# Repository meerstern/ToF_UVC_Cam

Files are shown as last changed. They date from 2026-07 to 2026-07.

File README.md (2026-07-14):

# ToF UVC Camera Board

## Overview 
  * This is a ToF camera board equipped with the [AMS TMF8829 ToF sensor][1].  
  * Outputs 48x32 ToF data as a UVC webcam image.  
  * The microcontroller used is the RP2040.  
  * Source code using the Pico-SDK is available.
  * Measuring up to 1.4 m in high-resolution mode and up to 5.7 m in standard mode.

## Detailed Specifications
  * The USB port uses a Type-C connection.
  * The board is recognized as a UVC (USB Video Class) device with a resolution of 128x96.
  * The ToF resolution is 48x32 as a UVC webcam image.
  * It is displayed scaled up by a factor of two(96x64).
  * Measuring up to 1.4 m in high-resolution mode(SW3 SEN ON)
  * Measuring up to 5.7 m in standard mode(SW3 SEN OFF)
  * Switch the color scale between absolute(SW3 ABS ON) and relative modes(SW3 ABS OFF).
  * In the relative mode, the color scale is calculated based on the overall maximum and minimum values.
  * For absolute mode, the color scale is calculated based on a minimum of 0 and a maximum of 1.4 m in high-resolution mode, or 5.7 m in normal mode.
  * If horizontally flip the output image, please flash the `UVC_RP2040_XXXXXX_vXX_Mirror.uf2` file.
  * In the code, enable `MIRRR_OUTPUT_MODE` in `UVC_RP2040.h`.
  * If the confidence value is less than 10, it will be displayed in black. 
  * The frame rate depends on the conditions, but it is around 8 FPS.
  * 80° FOV, 1cm minimum distance and 0.25 mm resolution
  * Power 5V/0.2A from USB Type-C Port
  * The maximum range of 11m is supported only at 8x8 resolution; this board does not support it.
  * The board size is 40mm x50 mm, the hole size is M3x4, the hole pitch is 34mm x44mm.
  * The sensor area on the board becomes hot. Please be careful.   

## Laser eye safety
The TMF8829 is designed to meet the Class 1 laser safety limits including single faults in
compliance with IEC / EN 60825-1:2014, EN 60825-1:2014+A11:2021 and Class 1 consumer
laser product according to EN 50689:2021.

## Updating the firmware
  * Connect the device to a PC (or similar) via USB Type-C.
  * Then press the RST button while holding down the BOOT button.
  * The device will be recognized as a USB drive.  
  * You can update the firmware by copying the firmware file(*.uf2) to the recognized USB drive.

## Appearance and examples
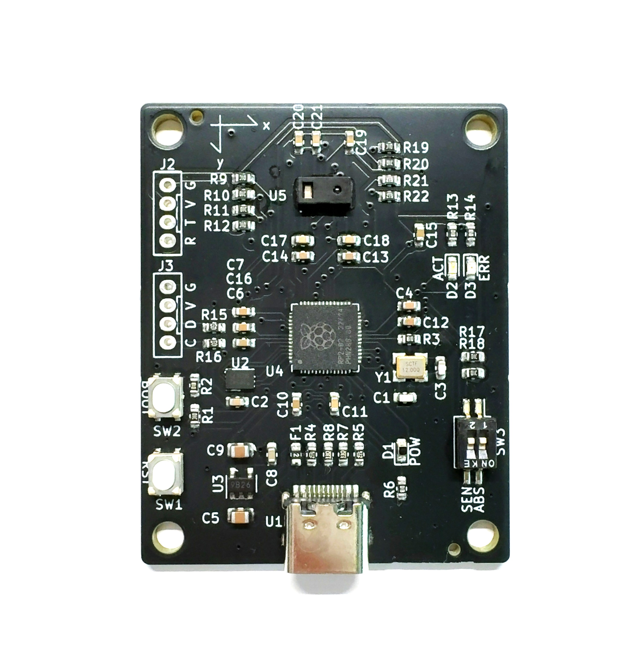
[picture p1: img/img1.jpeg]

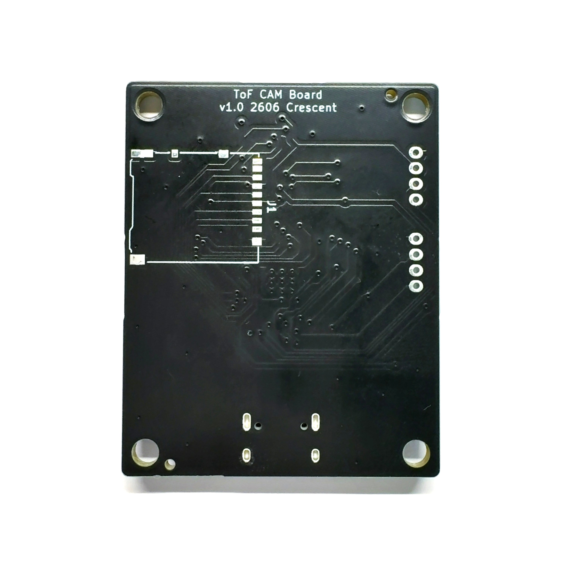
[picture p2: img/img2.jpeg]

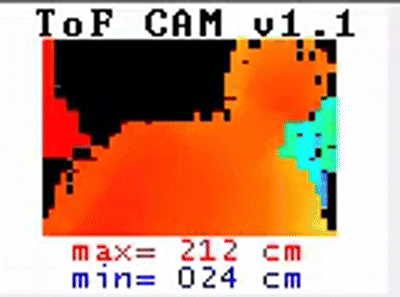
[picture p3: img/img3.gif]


[1]: https://ams-osram.com/ja/products/sensor-solutions/direct-time-of-flight-sensors-dtof/ams-tmf8829-48x32-multi-zone-time-of-flight-sensor

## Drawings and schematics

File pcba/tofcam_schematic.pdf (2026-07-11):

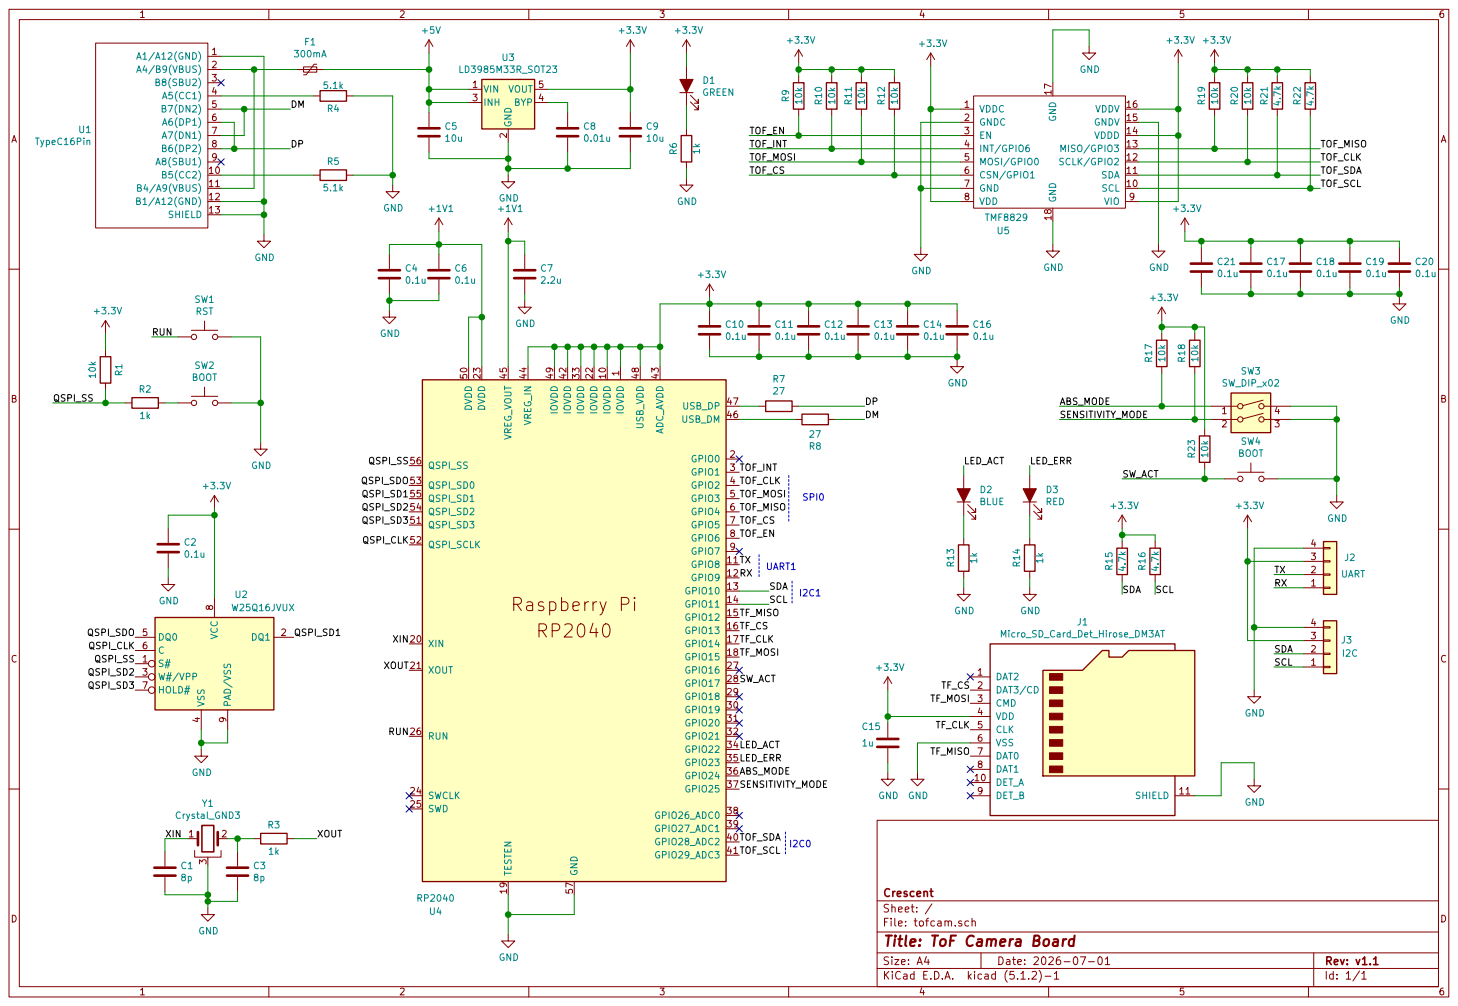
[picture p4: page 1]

1 IOVDD 10 GPIO8 11 GPIO9 12 GPIO10 13 GPIO11 14 GPIO12 15 GPIO13 16 GPIO14 17 GPIO15 18 TESTEN 19 GPIO0 2 XIN 20 XOUT 21 IOVDD 22 DVDD 23 SWCLK 24 SWD 25 RUN 26 GPIO16 27 GPIO17 28 GPIO18 29 GPIO1 3 GPIO19 30 GPIO20 31 GPIO21 32 IOVDD 33 GPIO22 34 GPIO23 35 GPIO24 36 GPIO25 37 GPIO26_ADC0 38 GPIO27_ADC1 39 GPIO2 4 GPIO28_ADC2 40 GPIO29_ADC3 41 IOVDD 42 ADC_AVDD 43 VREG_IN 44 VREG_VOUT 45 USB_DM 46 USB_DP 47 USB_VDD 48 IOVDD 49 GPIO3 5 DVDD 50 QSPI_SD3 51 QSPI_SCLK 52 QSPI_SD0 53 QSPI_SD2 54 QSPI_SD1 55 QSPI_SS 56 GND 57 GPIO4 6 GPIO5 7 GPIO6 8 GPIO7 9 U4 RP2040

File: tofcam.sch Sheet: / Crescent

Id: 1/1 Title: ToF Camera Board

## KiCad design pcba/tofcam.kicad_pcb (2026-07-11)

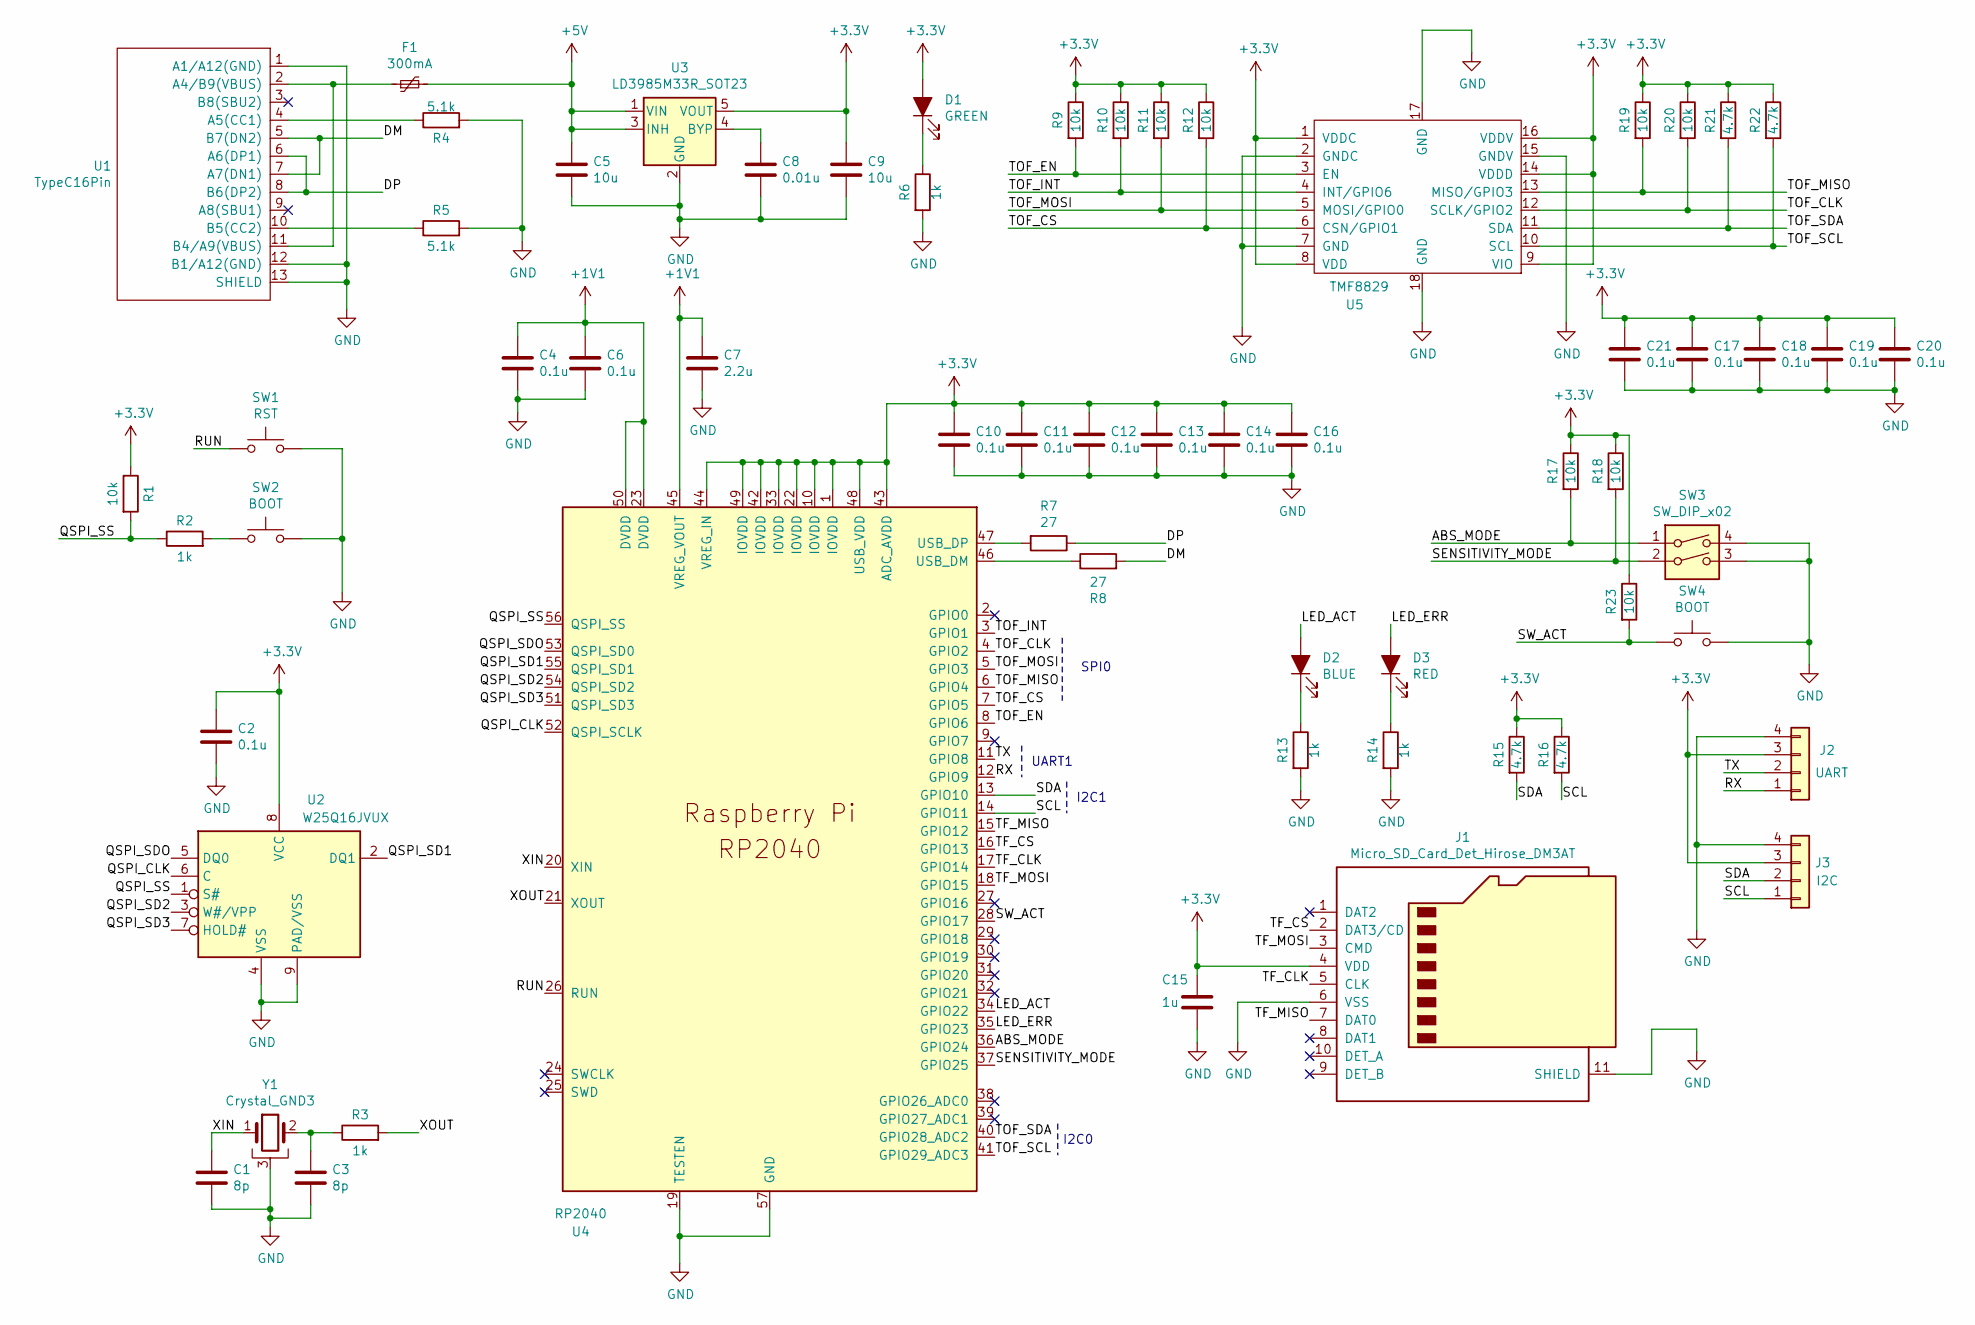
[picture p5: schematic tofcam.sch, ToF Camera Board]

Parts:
C1, C3: 8p; C_0603_1608Metric
C2, C4, C6, C10, C11, C12, C13, C14, C16, C17, C18, C19, C20, C21: 0.1u; C_0603_1608Metric
C5, C9: 10u; C_0805_2012Metric
C7: 2.2u; C_0603_1608Metric
C8: 0.01u; C_0603_1608Metric
C15: 1u; C_0603_1608Metric
D1: GREEN; LED_0603_1608Metric
D2: BLUE; LED_0603_1608Metric
D3: RED; LED_0603_1608Metric
F1: 300mA; Fuse_0603_1608Metric
J1: Micro_SD_Card_Det_Hirose_DM3AT; microSD_HC_Hirose_DM3AT-SF-PEJM5
J2: UART; GROVE
J3: I2C; GROVE
R1, R9, R10, R11, R12, R17, R18, R19, R20, R23: 10k; R_0603_1608Metric
R2, R3, R6, R13, R14: 1k; R_0603_1608Metric
R4, R5: 5.1k; R_0603_1608Metric
R7, R8: 27; R_0603_1608Metric
R15, R16, R21, R22: 4.7k; R_0603_1608Metric
SW1: RST; SKRPACE010
SW2, SW4: BOOT; SKRPACE010
SW3: SW_DIP_x02; SW_DIP_SPSTx02_Slide_Copal_CHS-02B_W7.62mm_P1.27mm
U1: TypeC16Pin; TypeC_16Pin
U2: W25Q16JVUX; SON-8-1EP_3x2mm_P0.5mm_EP1.4x1.6mm
U3: LD3985M33R_SOT23; SOT-23-5
U4: RP2040; RP2040-QFN-56
U5: TMF8829
Y1: Crystal_GND3; FA238V

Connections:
+1V1: C4.1, C6.1, C7.1, U4.23 (DVDD), U4.45 (VREG_VOUT), U4.50 (DVDD)
+3V3: C2.1, C9.1, C10.1, C11.1, C12.1, C13.1, C14.1, C15.1, C16.1, C17.1, C18.1, C19.1, C20.1, C21.1, D1.2 (A), J1.4 (VDD), J2.3, J3.3, R1.1, R9.1, R10.1, R11.1, R12.1, R15.1, R16.1, R17.1, R18.1, R19.1, R20.1, R21.1, R22.1, R23.1, U2.8 (VCC), U3.5 (VOUT), U4.1 (IOVDD), U4.10 (IOVDD), U4.22 (IOVDD), U4.33 (IOVDD), U4.42 (IOVDD), U4.43 (ADC_AVDD), U4.44 (VREG_IN), U4.48 (USB_VDD), U4.49 (IOVDD), U5.1 (VDDC), U5.8 (VDD), U5.9 (VIO), U5.14 (VDDD), U5.16 (VDDV)
+5V: C5.1, F1.2, U3.1 (VIN), U3.3 (INH)
/ABS_MODE: R17.2, SW3.1, U4.36 (GPIO24)
/DM: R8.2, U1.5 (B7(DN2)), U1.7 (A7(DN1))
/DP: R7.1, U1.6 (A6(DP1)), U1.8 (B6(DP2))
/LED_ACT: D2.2 (A), U4.34 (GPIO22)
/LED_ERR: D3.2 (A), U4.35 (GPIO23)
/QSPI_CLK: U2.6 (C), U4.52 (QSPI_SCLK)
/QSPI_SD1: U2.2 (DQ1), U4.55 (QSPI_SD1)
/QSPI_SD2: U2.3 (W#/VPP), U4.54 (QSPI_SD2)
/QSPI_SD3: U2.7 (HOLD#), U4.51 (QSPI_SD3)
/QSPI_SDO: U2.5 (DQ0), U4.53 (QSPI_SD0)
/QSPI_SS: R1.2, R2.1, U2.1 (S#), U4.56 (QSPI_SS)
/RUN: SW1.1, U4.26 (RUN)
/RX: J2.1, U4.12 (GPIO9)
/SCL: J3.1, R16.2, U4.14 (GPIO11)
/SDA: J3.2, R15.2, U4.13 (GPIO10)
/SENSITIVITY_MODE: R18.2, SW3.2, U4.37 (GPIO25)
/SW_ACT: R23.2, SW4.1, U4.28 (GPIO17)
/TF_CLK: J1.5 (CLK), U4.17 (GPIO14)
/TF_CS: J1.2 (DAT3/CD), U4.16 (GPIO13)
/TF_MISO: J1.7 (DAT0), U4.15 (GPIO12)
/TF_MOSI: J1.3 (CMD), U4.18 (GPIO15)
/TOF_CLK: R20.2, U4.4 (GPIO2), U5.12 (SCLK/GPIO2)
/TOF_CS: R12.2, U4.7 (GPIO5), U5.6 (CSN/GPIO1)
/TOF_EN: R9.2, U4.8 (GPIO6), U5.3 (EN)
/TOF_INT: R10.2, U4.3 (GPIO1), U5.4 (INT/GPIO6)
/TOF_MISO: R19.2, U4.6 (GPIO4), U5.13 (MISO/GPIO3)
/TOF_MOSI: R11.2, U4.5 (GPIO3), U5.5 (MOSI/GPIO0)
/TOF_SCL: R22.2, U4.41 (GPIO29_ADC3), U5.10 (SCL)
/TOF_SDA: R21.2, U4.40 (GPIO28_ADC2), U5.11 (SDA)
/TX: J2.2, U4.11 (GPIO8)
/XIN: C1.1, U4.20 (XIN), Y1.1
/XOUT: R3.2, U4.21 (XOUT)
GND: C1.2, C2.2, C3.2, C4.2, C5.2, C6.2, C7.2, C8.2, C9.2, C10.2, C11.2, C12.2, C13.2, C14.2, C15.2, C16.2, C17.2, C18.2, C19.2, C20.2, C21.2, J1.6 (VSS), J1.11 (SHIELD), J2.4, J3.4, R4.2, R5.2, R6.2, R13.2, R14.2, SW1.2, SW2.2, SW3.3, SW3.4, SW4.2, U1.1 (A1/A12(GND)), U1.12 (B1/A12(GND)), U1.13 (SHIELD), U2.4 (VSS), U2.9 (PAD/VSS), U3.2 (GND), U4.19 (TESTEN), U4.57 (GND), U5.2 (GNDC), U5.7 (GND), U5.15 (GNDV), U5.17 (GND), U5.18 (GND), Y1.3
unnamed: C3.1, R3.1, Y1.2
unnamed: C8.1, U3.4 (BYP)
unnamed: D1.1 (K), R6.1
unnamed: D2.1 (K), R13.1
unnamed: D3.1 (K), R14.1
unnamed: F1.1, U1.2 (A4/B9(VBUS)), U1.11 (B4/A9(VBUS))
unnamed: R2.2, SW2.1
unnamed: R4.1, U1.4 (A5(CC1))
unnamed: R5.1, U1.10 (B5(CC2))
unnamed: R7.2, U4.47 (USB_DP)
unnamed: R8.1, U4.46 (USB_DM)

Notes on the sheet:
I2C0
SPI0
UART1
I2C1

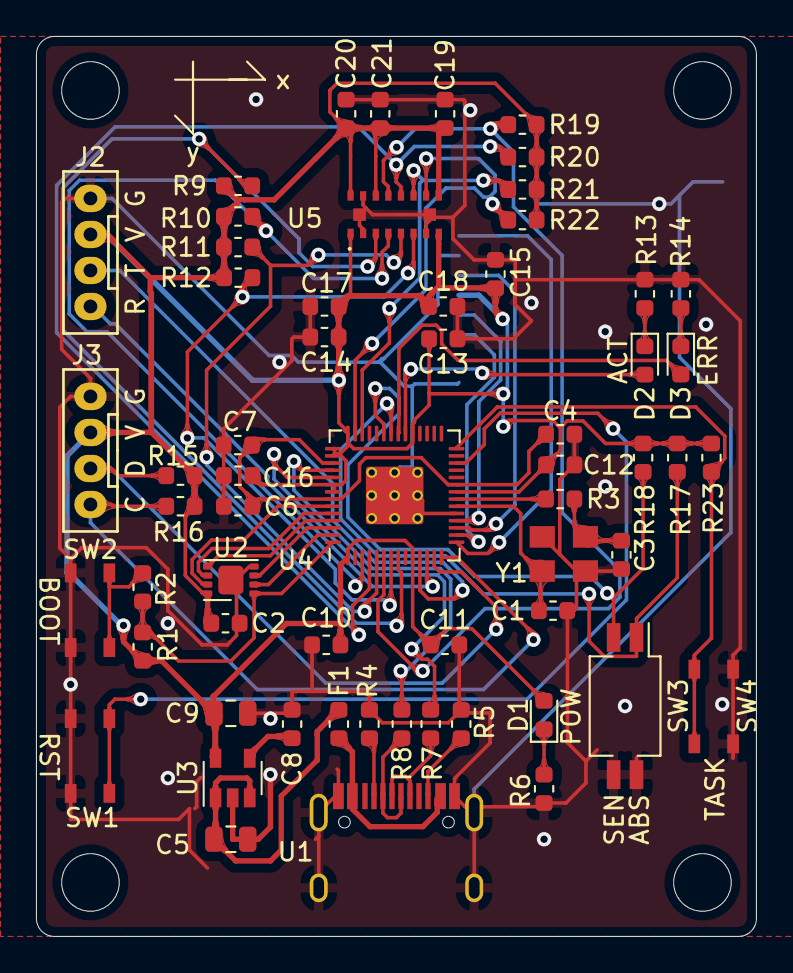
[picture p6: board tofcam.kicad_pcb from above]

Board: 2 copper layers, 40.0 x 50.0 mm, 65 parts (1 on the bottom side), 47 nets.

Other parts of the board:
REF1, REF2, REF3, REF4: MountingHole_3.2mm_M3

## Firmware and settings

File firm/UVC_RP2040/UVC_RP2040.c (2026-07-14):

/*
 * The MIT License (MIT)
 *
 * Copyright (c) 2019 Ha Thach (tinyusb.org)
 *
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
 */


#include <stdio.h>
#include <stdlib.h>
#include <stdbool.h>
#include <string.h>
#include <pico/stdlib.h>
#include <pico/rand.h>
#include <pico/multicore.h>

#include "bsp/board_api.h"
#include "tusb.h"
#include "usb_descriptors.h"
#include "ugui.h"
#include "UVC_RP2040.h"
#include "tmf8829.h"
#include "tmf8829_app.h"
#include "tmf8829_image.h"

UG_GUI gui;

static uint16_t guiBuff[FRAME_WIDTH*FRAME_HEIGHT];//RGB565

volatile uint8_t  tofBuff[TOF_PIX_WIDTH*TOF_PIX_HEIGHT*TOF_PIX_BYTES];
volatile uint16_t tofBuffIndex;
volatile bool     hasTofData = false;
volatile uint8_t  tofIndex;           //Index for interlace mode
static   bool     isTofReady = false;
         char     maxMinStr[40] = {'\0'};

#ifndef CFG_EXAMPLE_VIDEO_READONLY
// YUY2 frame buffer
static uint8_t frame_buffer[FRAME_WIDTH * FRAME_HEIGHT * 16 / 8];
#endif

//--------------------------------------------------------------------+
// MACRO CONSTANT TYPEDEF PROTYPES
//--------------------------------------------------------------------+

/* Blink pattern
 * - 250 ms  : device not mounted
 * - 1000 ms : device mounted
 * - 2500 ms : device is suspended
 */
enum {
  BLINK_NOT_MOUNTED = 250,
  BLINK_MOUNTED = 1000,
  BLINK_SUSPENDED = 2500,
};

static uint32_t blink_interval_ms = BLINK_NOT_MOUNTED;

void led_blinking_task(void* param);
void usb_device_task(void *param);
void video_task(void* param);


void pset(UG_S16 x, UG_S16 y, UG_COLOR col)
{
  uint16_t pix = 1*(x + y*FRAME_WIDTH);  
  guiBuff[pix] = col;
}

void copyFrameBuff()
{
  uint32_t pixels = FRAME_WIDTH * FRAME_HEIGHT;
  uint8_t *dst = &frame_buffer[0];

  for(uint32_t i = 0; i < pixels; i += 2)
  {
    uint16_t p0 = guiBuff[i];
    uint16_t p1 = guiBuff[i + 1];
     
    int r0 = (p0 >> 11) << 3;
    int g0 = ((p0 >> 5) & 0x3F) << 2;
    int b0 = (p0 & 0x1F) << 3;

    int r1 = (p1 >> 11) << 3;
    int g1 = ((p1 >> 5) & 0x3F) << 2;
    int b1 = (p1 & 0x1F) << 3;

    
    uint8_t y0 = (77 * r0 + 150 * g0 + 29 * b0) >> 8;
    uint8_t y1 = (77 * r1 + 150 * g1 + 29 * b1) >> 8;

    int u0 = ((-43 * r0 - 85 * g0 + 128 * b0) >> 8) + 128;
    int v0 = ((128 * r0 -107 * g0 - 21 * b0) >> 8) + 128;

    int u1 = ((-43 * r1 - 85 * g1 + 128 * b1) >> 8) + 128;
    int v1 = ((128 * r1 -107 * g1 - 21 * b1) >> 8) + 128;

    uint8_t u = (u0 + u1) >> 1;
    uint8_t v = (v0 + v1) >> 1;

    *dst++ = y0;
    *dst++ = u;
    *dst++ = y1;
    *dst++ = v;
  }
}

uint16_t val2rgb565( uint16_t value, uint16_t min, uint16_t max)
{
    if(value < min) value = min;
    if(value > max) value = max;

    uint32_t v = 255-((uint32_t)(value - min) * 255)/(max - min);
    uint8_t r, g, b;

    if(v < 64)
    {
        r = 0;
        g = v * 4;
        b = 255;
    }
    else if(v < 128)
    {
        r = 0;
        g = 255;
        b = 255 - (v - 64) * 4;
    }
    else if(v < 192)
    {
        r = (v - 128) * 4;
        g = 255;
        b = 0;
    }
    else
    {
        r = 255;
        g = 255 - (v - 192) * 4;
        b = 0;
    }

    return 
        ((r & 0xF8) << 8) |
        ((g & 0xFC) << 3) |
        (b >> 3);
}

void makeInitGrid()
{
  //return;
  uint16_t x,y;
  for(y=0;y<TOF_PIX_HEIGHT-1;y++)
  {
    for(x=0;x<TOF_PIX_WIDTH-1;x++)
    {
      uint16_t color = get_rand_32();
      uint16_t x_pos = START_X_POS + CELL_SIZE*x;
      uint16_t y_pos = START_Y_POS + CELL_SIZE*y;
      UG_FillFrame(x_pos, y_pos, x_pos+CELL_SIZE, y_pos+CELL_SIZE, color); 

    }
  }
}

void makeScaleGrid()
{
  uint16_t x,y;
  for(y=0;y<TOF_PIX_HEIGHT;y++)
  {
    uint16_t x_pos = START_X_POS + CELL_SIZE*TOF_PIX_WIDTH+5;
    uint16_t y_pos = START_Y_POS + CELL_SIZE*y;
    uint16_t color = val2rgb565(2*START_Y_POS+CELL_SIZE*TOF_PIX_HEIGHT-y_pos, START_Y_POS, START_Y_POS+CELL_SIZE*TOF_PIX_HEIGHT);
    UG_FillFrame(x_pos, y_pos, x_pos+4*CELL_SIZE, y_pos+CELL_SIZE, color);     
  }
}

void updateGrid()
{
    if(hasTofData)
    {

      printf("\r\nIndex:%d \r\n",tofBuffIndex);

      uint16_t x,y;
      uint16_t dataSize = tofBuffIndex - TMF8829_FRAME_FOOTER_SIZE;
      static uint16_t max_distance = 0;
      static uint16_t min_distance = 5700;

      if(tofIndex==0)
      {
        max_distance = 0;
        min_distance = 5700;
      }

      //Search Max Min Value
      for(uint16_t idx = 0; idx < dataSize/3; idx++)
      {
          uint16_t distance = tofBuff[3*idx+0] + tofBuff[3*idx+1]*256;
          uint16_t confidence =  tofBuff[3*idx+2];
          
          if(confidence>10)
          {
            if(distance>max_distance)
              max_distance = distance;

            if(distance<min_distance)
              min_distance = distance;
          }
      }

      //Update Info
      if(tofIndex==0)
      {         
          uint16_t maxVal = max_distance*TMF8829_BIT2MM/10;//mm to cm 
          memset(maxMinStr, '\0', sizeof(maxMinStr));
          snprintf(maxMinStr,sizeof(maxMinStr),"max= %03d cm    ",maxVal);
          UG_SetForecolor(C_BLUE);
          UG_PutString(24,77,maxMinStr);

          uint16_t minVal = min_distance*TMF8829_BIT2MM/10;//mm to cm
          memset(maxMinStr, '\0', sizeof(maxMinStr));
          snprintf(maxMinStr,sizeof(maxMinStr),"min= %03d cm    ",minVal);
          UG_SetForecolor(C_RED);
          UG_PutString(24,86,maxMinStr);
      }

      if(gpio_get(SW_MODE_ABS)==0)
      {
        if(gpio_get(SW_MODE_SEN)==0)
        {
          max_distance = HIGH_ACC_MAX_RANGE/TMF8829_BIT2MM;
          min_distance = 0;
        }
        else
        {
          max_distance = NORMAL_MAX_RANGE/TMF8829_BIT2MM;
          min_distance = 0;
        }
      }

      //Update Grid Color
      for(uint16_t idx = 0; idx < dataSize/3; idx++)
      {
        uint16_t distance = tofBuff[3*idx+0] + tofBuff[3*idx+1]*256;
        uint16_t confidence =  tofBuff[3*idx+2];
        uint16_t color = val2rgb565(distance, min_distance, max_distance);
        
#ifdef MIRRR_OUTPUT_MODE
        uint16_t x = TOF_PIX_WIDTH - 1 - (idx % TOF_PIX_WIDTH);
#else
        uint16_t x = idx%TOF_PIX_WIDTH;
#endif  

        uint16_t y = 2*(idx/TOF_PIX_WIDTH) + tofIndex;  //Data is interlace
        uint16_t x_pos = START_X_POS + CELL_SIZE*x;
        uint16_t y_pos = START_Y_POS + CELL_SIZE*y;

        static  uint16_t distance_buf[4];
        static  uint16_t confidence_buf[4];

#ifdef MIRRR_OUTPUT_MODE
        if( x > 15 && x <20 ) //Some pix has bug, Skip Update in tofIndex == 0
        {
            if(y==2)
            {
              distance = distance_buf[x-16];
              confidence = confidence_buf[x-16];
              color = val2rgb565(distance, min_distance, max_distance);
            }
            else if(y==3)
            {
              distance_buf[x-16] = distance;
              confidence_buf[x-16] = confidence;
            }
        }
#else
        if( x > 27 && x <32 ) //Some pix has bug, Skip Update in tofIndex == 0
        {
            if(y==2)
            {
              distance = distance_buf[x-28];
              confidence = confidence_buf[x-28];
              color = val2rgb565(distance, min_distance, max_distance);
            }
            else if(y==3)
            {
              distance_buf[x-28] = distance;
              confidence_buf[x-28] = confidence;
            }
        }
#endif
  
          
        if(confidence>10)
          UG_FillFrame(x_pos, y_pos, x_pos+CELL_SIZE, y_pos+CELL_SIZE, color); 
        else
          UG_FillFrame(x_pos, y_pos, x_pos+CELL_SIZE, y_pos+CELL_SIZE, C_BLACK); 
          
      }
    }
}

void core1_main()
{
Restart:
  setupFn( TMF8829_LOG_LEVEL_ERROR, UART_BAUD_RATE, I2C_CLK_SPEED );//TMF8829_LOG_LEVEL_INFO//TMF8829_LOG_LEVEL_RESULTS//TMF8829_LOG_LEVEL_RESULTS_HEADER//TMF8829_LOG_LEVEL_ERROR
  sleep_ms(10);
  enable( tmf8829_image_start, tmf8829_image, tmf8829_image_length );
  sleep_ms(10);

  if(gpio_get(SW_MODE_SEN)==0)
  {
    preconfigure(TMF8829_CMD_STAT__cmd_stat__CMD_LOAD_CFG_48X32_HIGH_ACCURACY);
  }
  else
  {
    preconfigure(TMF8829_CMD_STAT__cmd_stat__CMD_LOAD_CFG_48X32);
  }
  
  sleep_ms(10);
  measure( );
  isTofReady = true;
  while (1) {
    int8_t res = loopFn();
    if(hasTofData)
    {
      gpio_put(LED_ACT, 1);
      gpio_put(LED_ERR, 0);
      updateGrid();
      tofBuffIndex = 0;
      hasTofData = false;  
    }

    if(res==0)//has Err 
    {
      gpio_put(LED_ACT, 0);
      gpio_put(LED_ERR, 1);
      goto Restart;
    }  
  }

}

//--------------------------------------------------------------------+
// Main
//--------------------------------------------------------------------+
int main(void) {
  board_init();
  stdio_init_all();

  gpio_init(LED_ACT);
  gpio_init(LED_ERR);
  gpio_init(SW_MODE_ABS);
  gpio_init(SW_MODE_SEN);

  gpio_set_dir(LED_ACT, GPIO_OUT);
  gpio_set_dir(LED_ERR, GPIO_OUT);
  gpio_set_dir(SW_MODE_ABS, GPIO_IN);
  gpio_set_dir(SW_MODE_SEN, GPIO_IN);

  gpio_put(LED_ACT, 1);
  gpio_put(LED_ERR, 1);

  uint32_t random_val = get_rand_32();

  memset(guiBuff, 0, sizeof(guiBuff));
  UG_Init(&gui, pset, FRAME_WIDTH, FRAME_HEIGHT);
  UG_FillScreen(C_WHITE);
  UG_SelectGUI(&gui);
  UG_FontSelect(&FONT_8X12);
  UG_SetForecolor(C_BLACK);
  UG_SetBackcolor(C_WHITE);

  char head[] = TOF_HEADER_VERSION;
  UG_PutString(12,1,head);
  UG_FontSelect(&FONT_6X10);
  makeInitGrid();
  makeScaleGrid();

  // init device stack on configured roothub port
  tusb_rhport_init_t dev_init = {
    .role = TUSB_ROLE_DEVICE,
    .speed = TUSB_SPEED_AUTO
  };
  tusb_init(BOARD_TUD_RHPORT, &dev_init);

  if (board_init_after_tusb) {
    board_init_after_tusb();
  }

  //TMF8829 Process Thread
  multicore_reset_core1();
  multicore_launch_core1(core1_main);

  gpio_put(LED_ACT, 0);
  gpio_put(LED_ERR, 0);

  while (1) {
    tud_task(); // tinyusb device task
    led_blinking_task(NULL);
    video_task(NULL);
  }

}

//--------------------------------------------------------------------+
// Device callbacks
//--------------------------------------------------------------------+

// Invoked when device is mounted
void tud_mount_cb(void) {
  blink_interval_ms = BLINK_MOUNTED;
}

// Invoked when device is unmounted
void tud_umount_cb(void) {
  blink_interval_ms = BLINK_NOT_MOUNTED;
}

// Invoked when usb bus is suspended
// remote_wakeup_en : if host allow us  to perform remote wakeup
// Within 7ms, device must draw an average of current less than 2.5 mA from bus
void tud_suspend_cb(bool remote_wakeup_en) {
  (void) remote_wakeup_en;
  blink_interval_ms = BLINK_SUSPENDED;
}

// Invoked when usb bus is resumed
void tud_resume_cb(void) {
  blink_interval_ms = tud_mounted() ? BLINK_MOUNTED : BLINK_NOT_MOUNTED;
}

//--------------------------------------------------------------------+
// USB Video
//--------------------------------------------------------------------+
static unsigned frame_num = 0;
static unsigned tx_busy = 0;
static unsigned interval_ms = 1000 / FRAME_RATE;

#ifdef CFG_EXAMPLE_VIDEO_READONLY
// For mcus that does not have enough SRAM for frame buffer, we use fixed frame data.
// To further reduce the size, we use MJPEG format instead of YUY2.
#include "images.h"

#if !defined(CFG_EXAMPLE_VIDEO_DISABLE_MJPEG)
static struct {
  uint32_t       size;
  uint8_t const *buffer;
} const frames[] = {
  {color_bar_0_jpg_len, color_bar_0_jpg},
  {color_bar_1_jpg_len, color_bar_1_jpg},
  {color_bar_2_jpg_len, color_bar_2_jpg},
  {color_bar_3_jpg_len, color_bar_3_jpg},
  {color_bar_4_jpg_len, color_bar_4_jpg},
  {color_bar_5_jpg_len, color_bar_5_jpg},
  {color_bar_6_jpg_len, color_bar_6_jpg},
  {color_bar_7_jpg_len, color_bar_7_jpg},
};
#endif

#else

// YUY2 frame buffer
//static uint8_t frame_buffer[FRAME_WIDTH * FRAME_HEIGHT * 16 / 8];

static void fill_color_bar(uint8_t* buffer, unsigned start_position) {
  /* EBU color bars: https://stackoverflow.com/questions/6939422 */
  static uint8_t const bar_color[8][4] = {
      /*  Y,   U,   Y,   V */
      { 235, 128, 235, 128}, /* 100% White */
      { 219,  16, 219, 138}, /* Yellow */
      { 188, 154, 188,  16}, /* Cyan */
      { 173,  42, 173,  26}, /* Green */
      {  78, 214,  78, 230}, /* Magenta */
      {  63, 102,  63, 240}, /* Red */
      {  32, 240,  32, 118}, /* Blue */
      {  16, 128,  16, 128}, /* Black */
  };
  uint8_t* p;

  /* Generate the 1st line */
  uint8_t* end = &buffer[FRAME_WIDTH * 2];
  unsigned idx = (FRAME_WIDTH / 2 - 1) - (start_position % (FRAME_WIDTH / 2));
  p = &buffer[idx * 4];
  for (unsigned i = 0; i < 8; ++i) {
    for (int j = 0; j < FRAME_WIDTH / (2 * 8); ++j) {
      memcpy(p, &bar_color[i], 4);
      p += 4;
      if (end <= p) {
        p = buffer;
      }
    }
  }

  /* Duplicate the 1st line to the others */
  p = &buffer[FRAME_WIDTH * 2];
  for (unsigned i = 1; i < FRAME_HEIGHT; ++i) {
    memcpy(p, buffer, FRAME_WIDTH * 2);
    p += FRAME_WIDTH * 2;
  }
}

#endif

void video_send_frame(void) {
  static unsigned start_ms = 0;
  static unsigned already_sent = 0;

  if (!tud_video_n_streaming(0, 0)) {
    already_sent = 0;
    frame_num = 0;
    return;
  }

  if (!already_sent) {
    already_sent = 1;
    tx_busy = 1;
    start_ms = board_millis();
#ifdef CFG_EXAMPLE_VIDEO_READONLY
    #if defined(CFG_EXAMPLE_VIDEO_DISABLE_MJPEG)
    tud_video_n_frame_xfer(0, 0, (void*)(uintptr_t)&frame_buffer[(frame_num % (FRAME_WIDTH / 2)) * 4],
                           FRAME_WIDTH * FRAME_HEIGHT * 16/8);
    #else
    tud_video_n_frame_xfer(0, 0, (void*)(uintptr_t)frames[frame_num % 8].buffer, frames[frame_num % 8].size);
    #endif
#else
    //fill_color_bar(frame_buffer, frame_num);
    if(isTofReady==false)
      makeInitGrid();
    copyFrameBuff();
    tud_video_n_frame_xfer(0, 0, (void*) frame_buffer, FRAME_WIDTH * FRAME_HEIGHT * 16 / 8);
#endif
  }

  unsigned cur = board_millis();
  if (cur - start_ms < interval_ms) return; // not enough time
  if (tx_busy) return;
  start_ms += interval_ms;
  tx_busy = 1;

#ifdef CFG_EXAMPLE_VIDEO_READONLY
  #if defined(CFG_EXAMPLE_VIDEO_DISABLE_MJPEG)
  tud_video_n_frame_xfer(0, 0, (void*)(uintptr_t)&frame_buffer[(frame_num % (FRAME_WIDTH / 2)) * 4],
                         FRAME_WIDTH * FRAME_HEIGHT * 16/8);
  #else
  tud_video_n_frame_xfer(0, 0, (void*)(uintptr_t)frames[frame_num % 8].buffer, frames[frame_num % 8].size);
  #endif
#else
  //fill_color_bar(frame_buffer, frame_num);
  if(isTofReady==false)
    makeInitGrid();
  copyFrameBuff();
  tud_video_n_frame_xfer(0, 0, (void*) frame_buffer, FRAME_WIDTH * FRAME_HEIGHT * 16 / 8);
#endif
}


void video_task(void* param) {
  (void) param;

  while(1) {
    video_send_frame();
    return;

  }
}

void tud_video_frame_xfer_complete_cb(uint_fast8_t ctl_idx, uint_fast8_t stm_idx) {
  (void) ctl_idx;
  (void) stm_idx;
  tx_busy = 0;
  /* flip buffer */
  //++frame_num;
}

int tud_video_commit_cb(uint_fast8_t ctl_idx, uint_fast8_t stm_idx,
                        video_probe_and_commit_control_t const* parameters) {
  (void) ctl_idx;
  (void) stm_idx;
  /* convert unit to ms from 100 ns */
  interval_ms = parameters->dwFrameInterval / 10000;
  return VIDEO_ERROR_NONE;
}

//--------------------------------------------------------------------+
// Blinking Task
//--------------------------------------------------------------------+
void led_blinking_task(void* param) {
  (void) param;
  static uint32_t start_ms = 0;
  static bool led_state = false;

  while (1) {

    if (board_millis() - start_ms < blink_interval_ms) return; // not enough time


    start_ms += blink_interval_ms;
    board_led_write(led_state);
    led_state = 1 - led_state; // toggle
  }
}

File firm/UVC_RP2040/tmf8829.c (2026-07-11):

/**************************************************************************************************
* Copyright � 2024 ams-OSRAM AG                                                                   *
* All rights are reserved.                                                                        *
*                                                                                                 *
* FOR FULL LICENSE TEXT SEE LICENSES-MIT.TXT                                                      *
*                                                                                                 *
**************************************************************************************************/

/* simple TMF8829 driver */

// --------------------------------------------------- includes ---------------------------------------------------
#include <string.h>
#include "tmf8829_shim.h"
#include "tmf8829.h"
#include "UVC_RP2040.h"

// --------------------------------------------------- defines for HW registers   ---------------------------------
#define I2C_DEVADDR 0xe0
#define I2C_DEVADDR__i2c_devaddr__SHIFT 1
#define I2C_DEVADDR__i2c_devaddr__WIDTH 7
#define I2C_DEVADDR__i2c_devaddr__RESET 65
#define I2C_DEVADDR__enab_ack_hdr_write__SHIFT 0
#define I2C_DEVADDR__enab_ack_hdr_write__WIDTH 1
#define I2C_DEVADDR__enab_ack_hdr_write__RESET 0
#define INT_STATUS 0xe1
#define INT_STATUS__int7__SHIFT 7
#define INT_STATUS__int7__WIDTH 1
#define INT_STATUS__int7__RESET 0
#define INT_STATUS__int6__SHIFT 6
#define INT_STATUS__int6__WIDTH 1
#define INT_STATUS__int6__RESET 0
#define INT_STATUS__int5__SHIFT 5
#define INT_STATUS__int5__WIDTH 1
#define INT_STATUS__int5__RESET 0
#define INT_STATUS__int4__SHIFT 4
#define INT_STATUS__int4__WIDTH 1
#define INT_STATUS__int4__RESET 0
#define INT_STATUS__int3__SHIFT 3
#define INT_STATUS__int3__WIDTH 1
#define INT_STATUS__int3__RESET 0
#define INT_STATUS__int2__SHIFT 2
#define INT_STATUS__int2__WIDTH 1
#define INT_STATUS__int2__RESET 0
#define INT_STATUS__int1__SHIFT 1
#define INT_STATUS__int1__WIDTH 1
#define INT_STATUS__int1__RESET 0
#define INT_STATUS__int0__SHIFT 0
#define INT_STATUS__int0__WIDTH 1
#define INT_STATUS__int0__RESET 0
#define INT_ENAB 0xe2
#define INT_ENAB__int7_enab__SHIFT 7
#define INT_ENAB__int7_enab__WIDTH 1
#define INT_ENAB__int7_enab__RESET 0
#define INT_ENAB__int6_enab__SHIFT 6
#define INT_ENAB__int6_enab__WIDTH 1
#define INT_ENAB__int6_enab__RESET 0
#define INT_ENAB__int5_enab__SHIFT 5
#define INT_ENAB__int5_enab__WIDTH 1
#define INT_ENAB__int5_enab__RESET 0
#define INT_ENAB__int4_enab__SHIFT 4
#define INT_ENAB__int4_enab__WIDTH 1
#define INT_ENAB__int4_enab__RESET 0
#define INT_ENAB__int3_enab__SHIFT 3
#define INT_ENAB__int3_enab__WIDTH 1
#define INT_ENAB__int3_enab__RESET 0
#define INT_ENAB__int2_enab__SHIFT 2
#define INT_ENAB__int2_enab__WIDTH 1
#define INT_ENAB__int2_enab__RESET 0
#define INT_ENAB__int1_enab__SHIFT 1
#define INT_ENAB__int1_enab__WIDTH 1
#define INT_ENAB__int1_enab__RESET 0
#define INT_ENAB__int0_enab__SHIFT 0
#define INT_ENAB__int0_enab__WIDTH 1
#define INT_ENAB__int0_enab__RESET 0
#define ID 0xe3
#define ID__device_id__SHIFT 0
#define ID__device_id__WIDTH 8
#define ID__device_id__RESET 158
#define REVID 0xe4
#define REVID__rev_id__SHIFT 0
#define REVID__rev_id__WIDTH 3
#define REVID__rev_id__RESET 0
#define RESET 0xf7
#define RESET__hard_reset__SHIFT 7
#define RESET__hard_reset__WIDTH 1
#define RESET__hard_reset__RESET 0
#define RESET__soft_reset__SHIFT 6
#define RESET__soft_reset__WIDTH 1
#define RESET__soft_reset__RESET 0
#define RESET__reset_reason_coldstart__SHIFT 5
#define RESET__reset_reason_coldstart__WIDTH 1
#define RESET__reset_reason_coldstart__RESET 1
#define RESET__reset_reason_hard_reset__SHIFT 4
#define RESET__reset_reason_hard_reset__WIDTH 1
#define RESET__reset_reason_hard_reset__RESET 0
#define RESET__reset_reason_soft_reset__SHIFT 3
#define RESET__reset_reason_soft_reset__WIDTH 1
#define RESET__reset_reason_soft_reset__RESET 0
#define RESET__reset_reason_host__SHIFT 1
#define RESET__reset_reason_host__WIDTH 1
#define RESET__reset_reason_host__RESET 0
#define RESET__reset_reason_timer__SHIFT 0
#define RESET__reset_reason_timer__WIDTH 1
#define RESET__reset_reason_timer__RESET 0
#define ENABLE 0xf8
#define ENABLE__cpu_ready__SHIFT 7
#define ENABLE__cpu_ready__WIDTH 1
#define ENABLE__cpu_ready__RESET 0
#define ENABLE__bootwithoutpll__SHIFT 6
#define ENABLE__bootwithoutpll__WIDTH 1
#define ENABLE__bootwithoutpll__RESET 0
#define ENABLE__powerup_select__SHIFT 4
#define ENABLE__powerup_select__WIDTH 2
#define ENABLE__powerup_select__RESET 0
// Enumeration for powerup_select
#define ENABLE__powerup_select__NO_OVERRIDE 0 // No override - use content of fuses to select - see boot-matrix above (default)
#define ENABLE__powerup_select__FORCE_BOOTMONITOR 1 // Force bootmonitor - ignore fuses and wait for host commands
#define ENABLE__powerup_select__RAM 2 // execute AORAM bootrecords and then set IVT to 0x10000 (base of RAM)to RAM and start whatever application is there - no checks are done!! - application in RAM has to check for reset-reason to know how to proceed
#define ENABLE__poff__SHIFT 3
#define ENABLE__poff__WIDTH 1
#define ENABLE__poff__RESET 0
#define ENABLE__pon__SHIFT 2
#define ENABLE__pon__WIDTH 1
#define ENABLE__pon__RESET 1
#define ENABLE__timed_standby_mode__SHIFT 1
#define ENABLE__timed_standby_mode__WIDTH 1
#define ENABLE__timed_standby_mode__RESET 0
#define ENABLE__standby_mode__SHIFT 0
#define ENABLE__standby_mode__WIDTH 1
#define ENABLE__standby_mode__RESET 0
#define FIFOSTATUS 0xfa
#define FIFOSTATUS__fifo_direction__SHIFT 0
#define FIFOSTATUS__fifo_direction__WIDTH 1
#define FIFOSTATUS__fifo_direction__RESET 0
#define FIFOSTATUS__fifo_dma_busy__SHIFT 1
#define FIFOSTATUS__fifo_dma_busy__WIDTH 1
#define FIFOSTATUS__fifo_dma_busy__RESET 0
#define FIFOSTATUS__txfifo_empty__SHIFT 2
#define FIFOSTATUS__txfifo_empty__WIDTH 1
#define FIFOSTATUS__txfifo_empty__RESET 1
#define FIFOSTATUS__rxfifo_full__SHIFT 3
#define FIFOSTATUS__rxfifo_full__WIDTH 1
#define FIFOSTATUS__rxfifo_full__RESET 0
#define FIFOSTATUS__txfifo_underrun__SHIFT 4
#define FIFOSTATUS__txfifo_underrun__WIDTH 1
#define FIFOSTATUS__txfifo_underrun__RESET 0
#define FIFOSTATUS__rxfifo_overrun__SHIFT 5
#define FIFOSTATUS__rxfifo_overrun__WIDTH 1
#define FIFOSTATUS__rxfifo_overrun__RESET 0
#define SYSTICK_0 0xfb
#define SYSTICK_0__hif_systick__SHIFT 0
#define SYSTICK_0__hif_systick__WIDTH 8
#define SYSTICK_0__hif_systick__RESET 0
#define SYSTICK_1 0xfc
#define SYSTICK_1__hif_systick__SHIFT 0
#define SYSTICK_1__hif_systick__WIDTH 8
#define SYSTICK_1__hif_systick__RESET 0
#define SYSTICK_2 0xfd
#define SYSTICK_2__hif_systick__SHIFT 0
#define SYSTICK_2__hif_systick__WIDTH 8
#define SYSTICK_2__hif_systick__RESET 0
#define SYSTICK_3 0xfe
#define SYSTICK_3__hif_systick__SHIFT 0
#define SYSTICK_3__hif_systick__WIDTH 8
#define SYSTICK_3__hif_systick__RESET 0
#define FIFO 0xff
#define FIFO__fifo_data__SHIFT 0
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
